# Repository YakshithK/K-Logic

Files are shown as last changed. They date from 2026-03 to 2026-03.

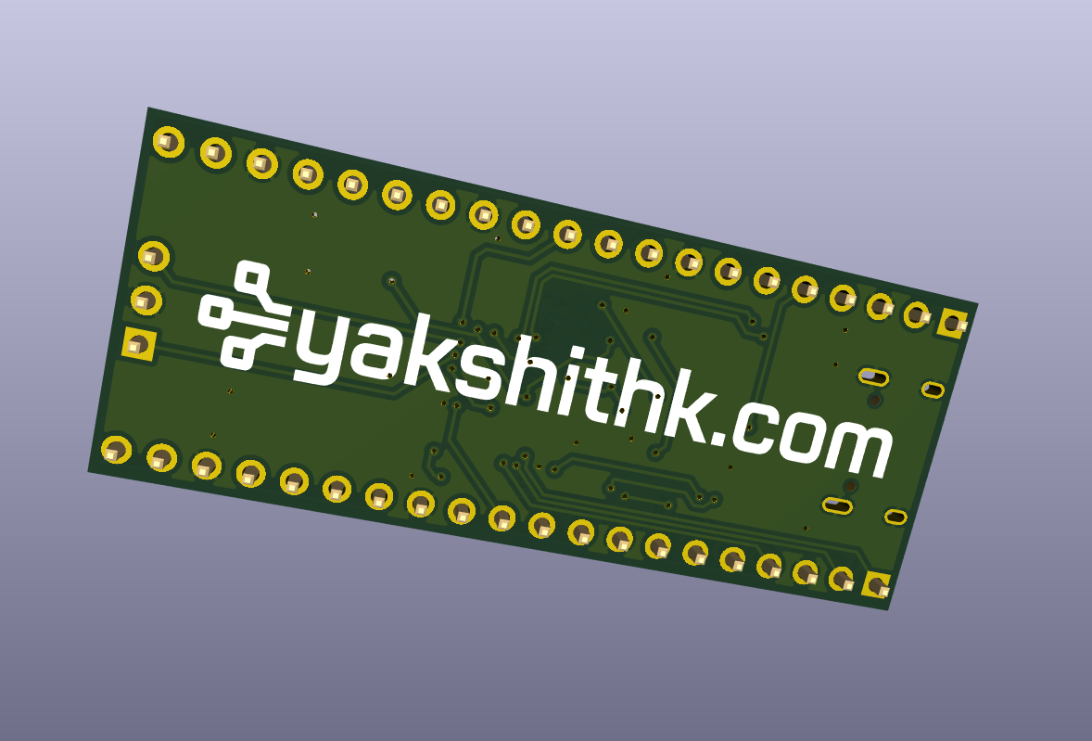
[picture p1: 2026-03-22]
Screenshots/Screenshot 2026-03-21 152902.png

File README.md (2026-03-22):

# K‑Logic Devboard

K‑Logic is a devboard I designed by following the Stasis starter devboard guide. my first PCB that goes! [stasis.hackclub](https://stasis.hackclub.com)

## What this is

- USB‑C powered devboard built with an RP2040
- Designed using the Stasis starter project flow (schematic → layout → silkscreen → fabrication)

## How to use it

- Plug it in over USB‑C.  
- Flash your firmware onto the main microcontroller.  
- Use the headers to hook up whatever logic / stuff you want.

## Why I built it

I've always wanted to get into hardware tech in general and I knew PCBs were going to be my first project in hardware after I found out about Stasis.

## Project structure

- `Journal/` – build log entries for each step (schematic, layout, silkscreen, fabrication, etc.). [github](https://github.com/YakshithK/K-Logic)
- `prod/` – production ZIP I sent to JLCPCB (gerbers + fab files). [github](https://github.com/YakshithK/K-Logic)
- `prod-files/` – BOM, CPL, and other manufacturing‑related files. [github](https://github.com/YakshithK/K-Logic)
- `DRC.rpt` – final DRC report from KiCad. [github](https://github.com/YakshithK/K-Logic)

## Screenshots

I have a bunch of screenshots of:

- Schematic in KiCad  
- PCB layout & 3D view  
- Silkscreen art and labels  
- JLCPCB upload / PCBA screens  

Check the `Screenshots/` dir

## BOM (short version)

Full BOM with links is in `K-Logic-Devboard-BOM-JLCPCB_Assembly_Order.csv` and `prod-files/`

| Part | Value | Notes |
| --- | --- | --- |
| MCU | (see BOM)  | Main brain of the board |
| Flash memory | W25Q16JVUXIQ | External flash for storage |
| USB‑C connector | — | Power + data input |
| LDO regulator | — | Regulates USB power |
| Passives | various | Resistors, caps, etc. |

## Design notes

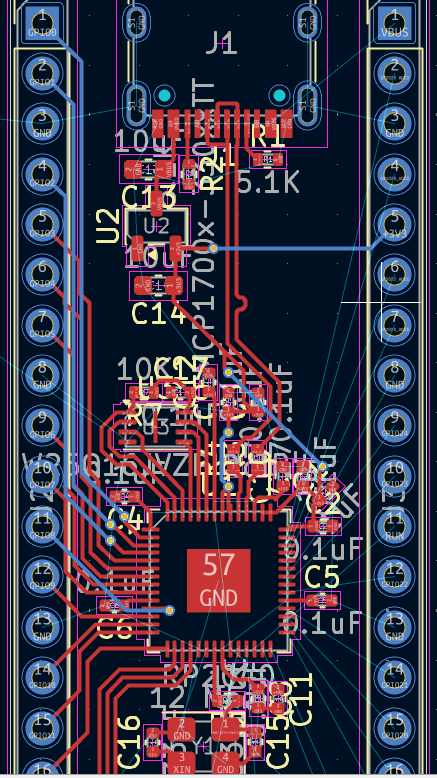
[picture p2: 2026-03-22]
Screenshots/Screenshot 2026-03-14 114329.png

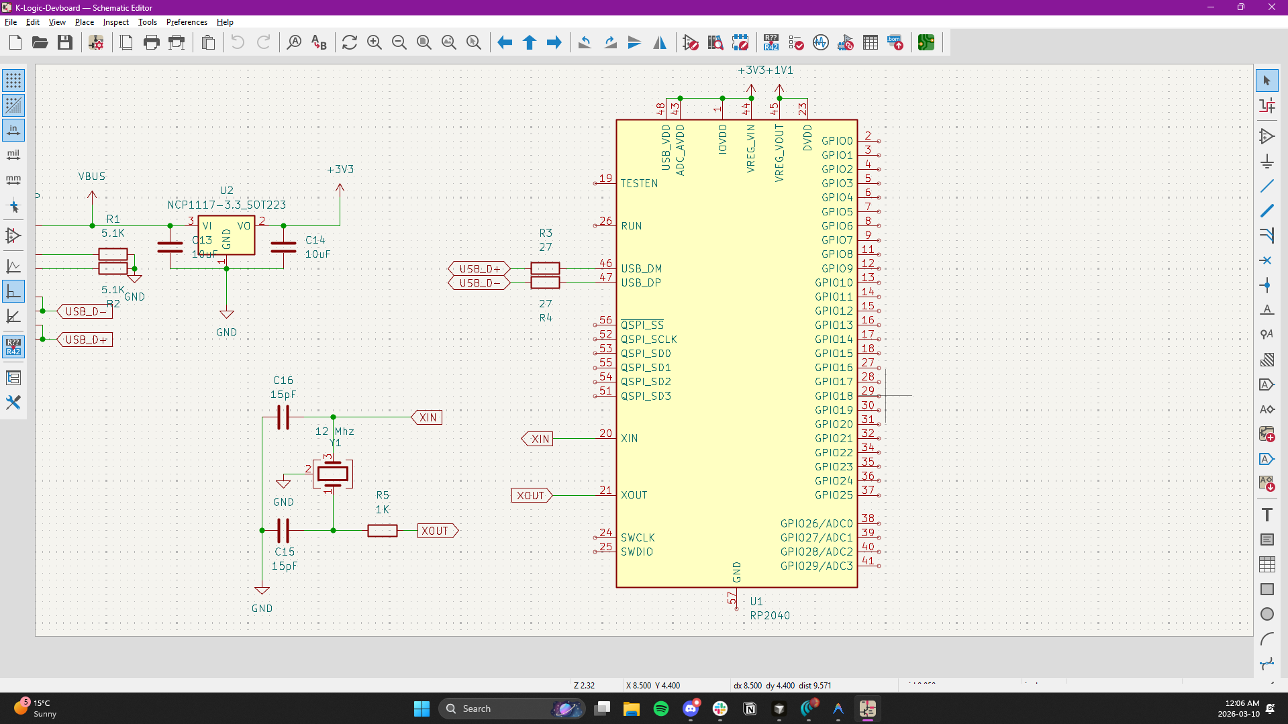
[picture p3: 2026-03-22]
Screenshots/Screenshot 2026-03-10 000638.png

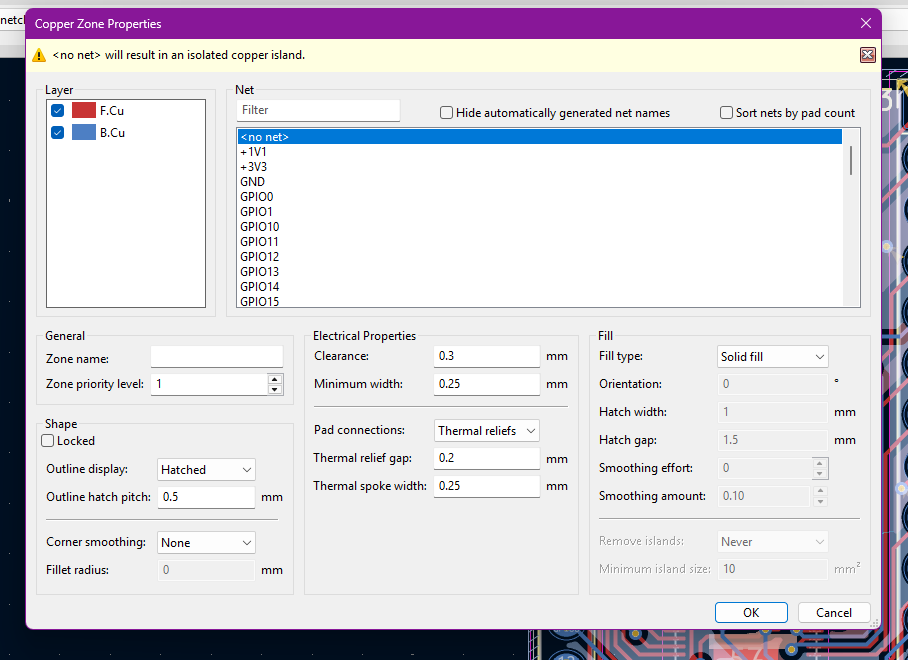
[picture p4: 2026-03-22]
Screenshots/Screenshot 2026-03-21 165424.png

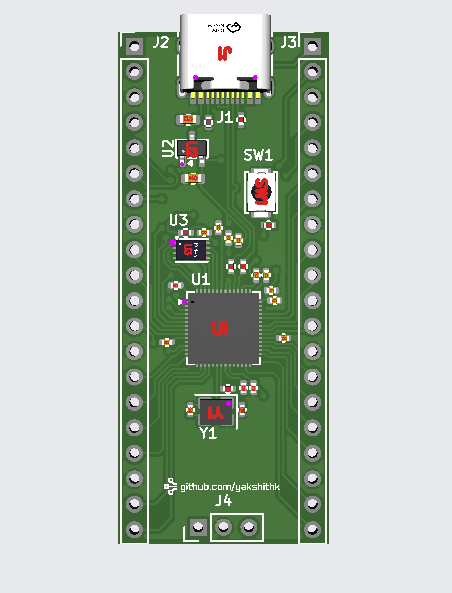
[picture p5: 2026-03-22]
Screenshots/Screenshot 2026-03-22 014045.png

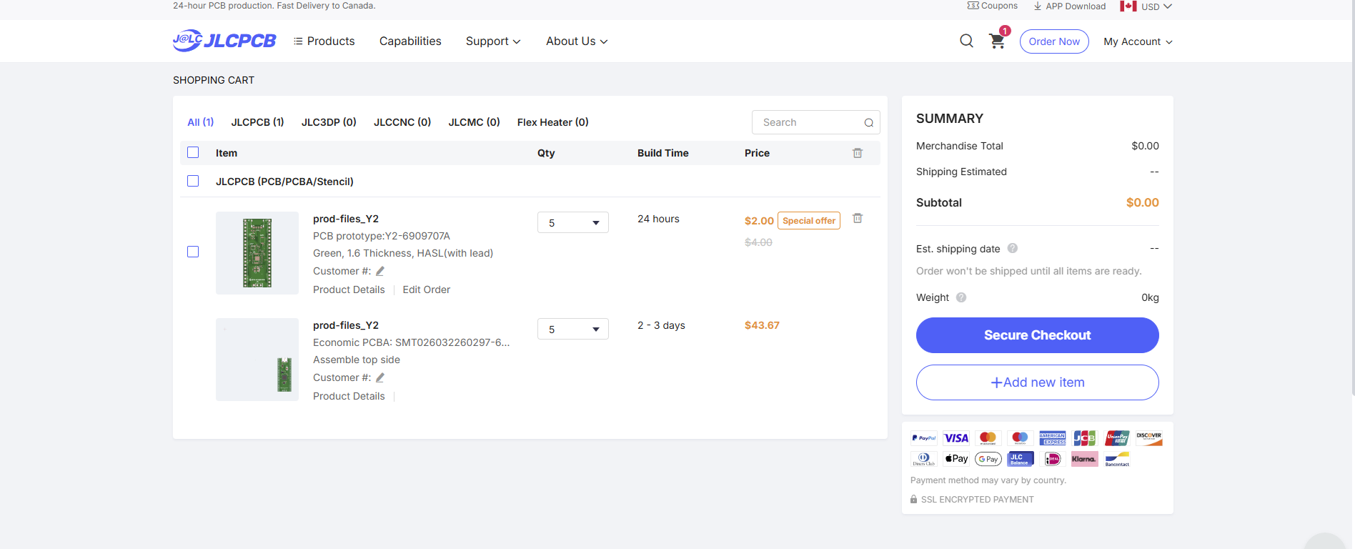
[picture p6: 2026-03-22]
Screenshots/Screenshot 2026-03-22 013410.png

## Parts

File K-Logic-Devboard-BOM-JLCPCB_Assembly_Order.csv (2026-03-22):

Top Designator | Bottom Designator | Comment | Footprint | JLCPCB Part # | Matches | Part # | Manufacturer | Footprint | Description | Category | Warning | JLCPCB Part # | Product link | Lib Type | Qty | Source | Total Price ($)
C10,C1 |  | 1uF | C_0402_1005Metric |  | Select by Customer | CL05A105KA5NQNC | Samsung Electro-Mechanics | 0402 | 1uF 25V X5R ±10% 0402 Multilayer Ceramic Capacitors MLCC - SMD/SMT ROHS | Multilayer Ceramic Capacitors MLCC - SMD/SMT |  | C52923 | https://jlcpcb.com/partdetail/53938-CL05A105KA5NQNC/C52923 | Basic | 20 | 20 JLCPCB | 0.08
C11,C5,C6,C2,C12,C9,C7,C17,C4,C8,C3 |  | 0.1uF | C_0402_1005Metric |  | Select by Customer | CL05B104KO5NNNC | Samsung Electro-Mechanics | 0402 | 100nF 16V X7R ±10% 0402 Multilayer Ceramic Capacitors MLCC - SMD/SMT ROHS | Multilayer Ceramic Capacitors MLCC - SMD/SMT | 1.The comment (CL05B104KO5NNNC) of this part does not match the one (0.1uF) provided in your BOM. Please confirm; | C1525 | https://jlcpcb.com/partdetail/1877-CL05B104KO5NNNC/C1525 | Basic | 65 | 65 JLCPCB | 0.0845
C14,C13 |  | 10uF | C_0603_1608Metric |  | Select by Customer | CL10A106KP8NNNC | Samsung Electro-Mechanics | 0603 | 10V 10uF X5R ±10% 0603 Multilayer Ceramic Capacitors MLCC - SMD/SMT ROHS | Multilayer Ceramic Capacitors MLCC - SMD/SMT |  | C19702 | https://jlcpcb.com/partdetail/20411-CL10A106KP8NNNC/C19702 | Basic | 20 | 20 JLCPCB | 0.144
C16,C15 |  | 33pF | C_0402_1005Metric |  | Select by Customer | 0402CG330J500NT | FH (Guangdong Fenghua Advanced Tech) | 0402 | 33pF 50V C0G ±5% 0402 Multilayer Ceramic Capacitors MLCC - SMD/SMT ROHS | Multilayer Ceramic Capacitors MLCC - SMD/SMT |  | C1562 | https://jlcpcb.com/partdetail/1914-0402CG330J500NT/C1562 | Basic | 20 | 20 JLCPCB | 0.024
J1 |  | USB_C_Receptacle_USB2.0_14P | USB_C_Receptacle_HRO_TYPE-C-31-M-12 |  | Select by Customer | TYPE-C-31-M-12 | Korean Hroparts Elec | SMD | -30℃~+80℃ 1 10,000 cycles 16P 20V 5A 7.35mm Female Surface Mount, Right Angle Type-C SMD USB Connectors ROHS | USB Connectors |  | C165948 | https://jlcpcb.com/partdetail/Korean_HropartsElec-TYPE_C_31_M12/C165948 | Extended | 5 | 5 JLCPCB | 0.906
J3,J2 |  | Conn_01x20 | PinHeader_1x20_P2.54mm_Vertical |  | Select by Customer | 2.54-1*20P直针 | BOOMELE(Boom Precision Elec) | 插件,P=2.54mm | -40℃~+105℃ 1 1x20P 2.54mm 20P 3A Black Brass Pin Header Through Hole Plugin,P=2.54mm Pin Headers ROHS | Pin Headers |  | C50981 | https://jlcpcb.com/partdetail/51993-2_54_1_20P/C50981 | Extended | 0 | 0 JLCPCB | 0
J4 |  | Conn_01x03 | PinHeader_1x03_P2.54mm_Vertical |  | Select by Customer | 1.27-1*3P针 | BOOMELE(Boom Precision Elec) | 插件,P=1.27mm | -55℃~+105℃ 1 1.27mm 1.7mm 1x3P 2.5mm 3A 3P 3mm Black Brass Pin Header Through Hole Plugin,P=1.27mm Pin Headers ROHS | Pin Headers |  | C24980 | https://jlcpcb.com/partdetail/25717-1_27_1_3P/C24980 | Extended | 0 | 0 JLCPCB | 0
R2,R1 |  | 5.1K | R_0402_1005Metric |  | Select by Customer | 0402WGF5101TCE | UNI-ROYAL(Uniroyal Elec) | 0402 | -55℃~+155℃ 5.1kΩ 50V 62.5mW Thick Film Resistor ±1% ±100ppm/℃ 0402 Chip Resistor - Surface Mount ROHS | Chip Resistor - Surface Mount |  | C25905 | https://jlcpcb.com/partdetail/26648-0402WGF5101TCE/C25905 | Basic | 20 | 20 JLCPCB | 0.016
R4,R3 |  | 27 | R_0402_1005Metric |  | Select by Customer | 0402WGF270JTCE | UNI-ROYAL(Uniroyal Elec) | 0402 | -55℃~+155℃ 27Ω 50V 62.5mW Thick Film Resistor ±1% ±100ppm/℃ 0402 Chip Resistor - Surface Mount ROHS | Chip Resistor - Surface Mount | 1.The comment (0402WGF270JTCE) of this part does not match the one (27) provided in your BOM. Please confirm; | C25100 | https://jlcpcb.com/partdetail/25843-0402WGF270JTCE/C25100 | Extended | 22 | 22 JLCPCB | 0.0176
R5,R6 |  | 1K | R_0402_1005Metric |  | Select by Customer | 0402WGF1001TCE | UNI-ROYAL(Uniroyal Elec) | 0402 | -55℃~+155℃ 1kΩ 50V 62.5mW Thick Film Resistor ±1% ±100ppm/℃ 0402 Chip Resistor - Surface Mount ROHS | Chip Resistor - Surface Mount | 1.The comment (0402WGF1001TCE) of this part does not match the one (1K) provided in your BOM. Please confirm; | C11702 | https://jlcpcb.com/partdetail/12256-0402WGF1001TCE/C11702 | Basic | 20 | 20 JLCPCB | 0.014
R7 |  | 10K | R_0402_1005Metric |  | Select by Customer | 0402WGF1002TCE | UNI-ROYAL(Uniroyal Elec) | 0402 | -55℃~+155℃ 10kΩ 50V 62.5mW Thick Film Resistor ±1% ±100ppm/℃ 0402 Chip Resistor - Surface Mount ROHS | Chip Resistor - Surface Mount | 1.The comment (0402WGF1002TCE) of this part does not match the one (10K) provided in your BOM. Please confirm; | C25744 | https://jlcpcb.com/partdetail/26487-0402WGF1002TCE/C25744 | Basic | 20 | 20 JLCPCB | 0.016
SW1 |  | SW_Push | SW_Push_SPST_NO_Alps_SKRK |  | Select by Customer | TS-1088-AR02016 | XUNPU | SMD,4x3mm | -30℃~+80℃ 1.6N 100,000 cycles 12V 2mm 3mm 4mm 50mA Black Round Button SMD(SMT) Tab SPST Surface Mount,Vertical Without Bracket SMD,4x3mm Tactile Switches ROHS | Tactile Switches |  | C720477 | https://jlcpcb.com/partdetail/XUNPU-TS_1088AR02016/C720477 | Basic | 9 | 9 JLCPCB | 0.4815
U1 |  | RP2040 | QFN-56-1EP_7x7mm_P0.4mm_EP3.2x3.2mm |  | Select by Customer | RP2040 | Raspberry Pi | LQFN-56(7x7) | 12bit 133MHz 30 LQFN-56(7x7) Microcontrollers (MCU/MPU/SOC) ROHS | Microcontrollers (MCU/MPU/SOC) |  | C2040 | https://jlcpcb.com/partdetail/RaspberryPi-RP2040/C2040 | Extended | 5 | 5 JLCPCB | 4.8295
U2 |  | MCP1700x-330xxTT | SOT-23-3 |  | Select by Customer | MCP1700T-3302E/TT | Microchip Tech | SOT-23 | -40℃~+125℃@(Tj) 1 1.6uA 178mV@(250mA) 250mA 3.3V 44dB@(100Hz) 6V Fixed Over Temperature Protection、Short Circuit Protection Positive SOT-23 Voltage Regulators - Linear, Low Drop Out (LDO) Regulators ROHS | Voltage Regulators - Linear, Low Drop Out (LDO) Regulators |  | C39051 | https://jlcpcb.com/partdetail/MicrochipTech-MCP1700T_3302ETT/C39051 | Extended | 5 | 5 JLCPCB | 1.864
U3 |  | W25Q16JVZPIQTR | Winbond_USON-8-1EP_3x2mm_P0.5mm_EP0.2x1.6mm |  | Select by Customer | W25Q16JVUXIQ | Winbond Elec | USON-8-EP(2x3) | -40℃~+85℃ 100,000 cycles 10uA 133MHz 16Mbit 2.7V~3.6V 20 Years 3ms SPI USON-8-EP(2x3) NOR FLASH ROHS | NOR FLASH | 1.The comment (W25Q16JVUXIQ) of this part does not match the one (W25Q16JVZPIQTR) provided in your BOM. Please confirm; | C2843335 | https://jlcpcb.com/partdetail/WinbondElec-W25Q16JVUXIQ/C2843335 | Extended | 5 | 5 JLCPCB | 8.331
Y1 |  | 12Mhz | Crystal_SMD_3225-4Pin_3.2x2.5mm |  | Select by Customer | X322512MSB4SI | YXC Crystal Oscillators | SMD3225-4P | -40℃~+85℃ 12MHz 20pF Crystal Oscillator ±10ppm ±20ppm SMD3225-4P Crystals ROHS | Crystals |  | C9002 | https://jlcpcb.com/partdetail/YXC_CrystalOscillators-X322512MSB4SI/C9002 | Basic | 9 | 9 JLCPCB | 0.6534

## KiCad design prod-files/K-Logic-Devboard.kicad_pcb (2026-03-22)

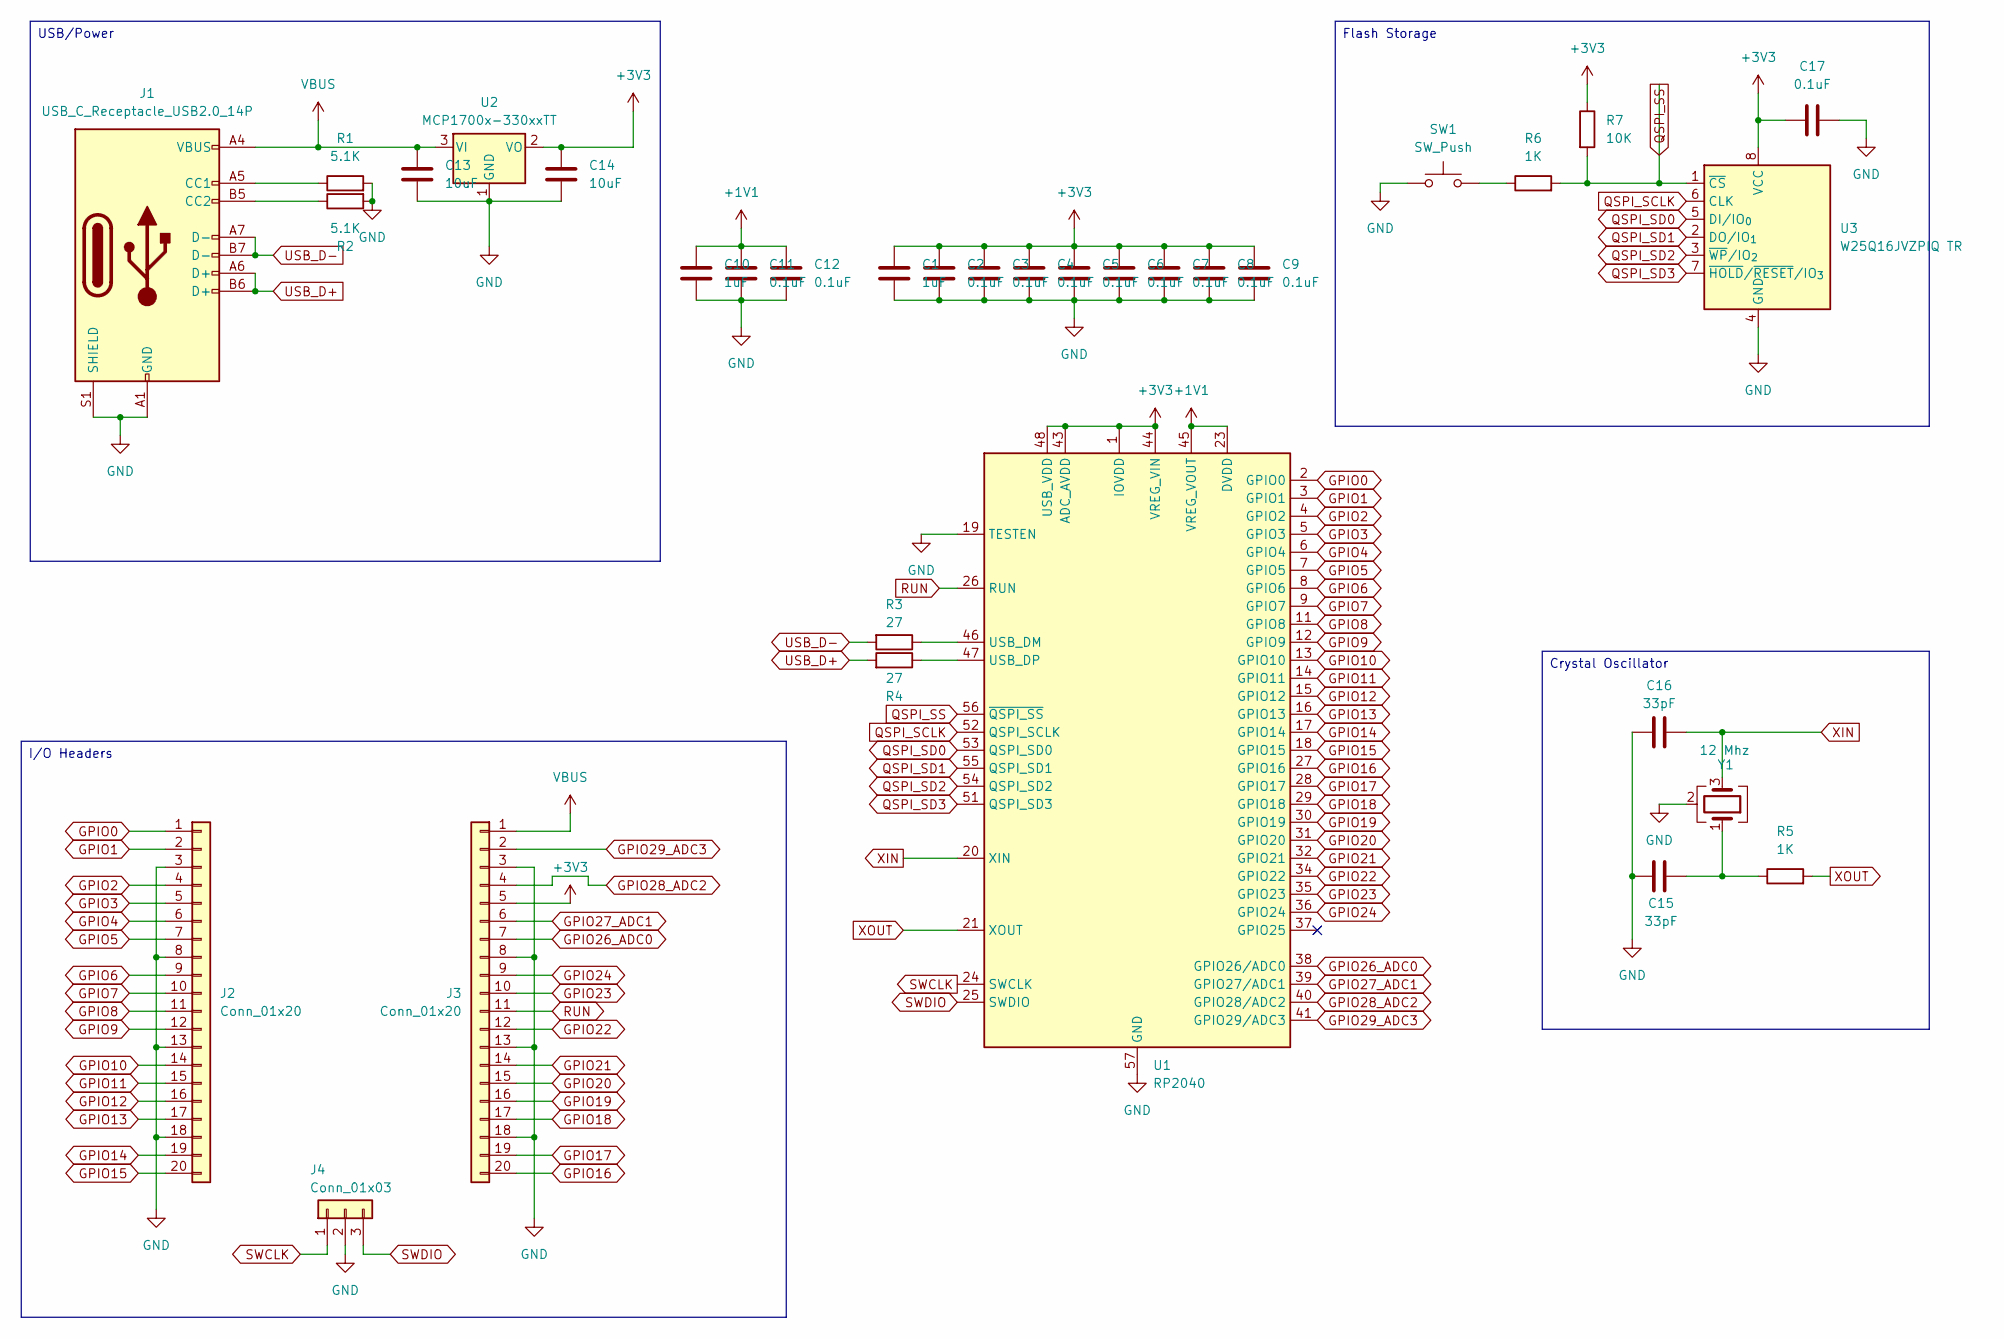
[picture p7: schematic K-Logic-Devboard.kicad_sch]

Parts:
C1, C10: 1uF; C_0402_1005Metric
C2, C3, C4, C5, C6, C7, C8, C9, C11, C12, C17: 0.1uF; C_0402_1005Metric
C13, C14: 10uF; C_0603_1608Metric
C15, C16: 33pF; C_0402_1005Metric
J1: USB_C_Receptacle_USB2.0_14P; USB_C_Receptacle_HRO_TYPE-C-31-M-12
J2, J3: Conn_01x20; PinHeader_1x20_P2.54mm_Vertical
J4: Conn_01x03; PinHeader_1x03_P2.54mm_Vertical
R1, R2: 5.1K; R_0402_1005Metric
R3, R4: 27; R_0402_1005Metric
R5, R6: 1K; R_0402_1005Metric
R7: 10K; R_0402_1005Metric
SW1: SW_Push; SW_Push_SPST_NO_Alps_SKRK
U1: RP2040; QFN-56-1EP_7x7mm_P0.4mm_EP3.2x3.2mm
U2: MCP1700x-330xxTT; SOT-23-3
U3: W25Q16JVZPIQ TR; Winbond_USON-8-1EP_3x2mm_P0.5mm_EP0.2x1.6mm
Y1: 12 Mhz; Crystal_SMD_3225-4Pin_3.2x2.5mm

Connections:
+1V1: C10.1, C11.1, C12.1, U1.23 (DVDD), U1.45 (VREG_VOUT), U1.50 (DVDD)
+3V3: C1.1, C2.1, C3.1, C4.1, C5.1, C6.1, C7.1, C8.1, C9.1, C14.1, C17.2, J3.5, R7.1, U1.1 (IOVDD), U1.10 (IOVDD), U1.22 (IOVDD), U1.33 (IOVDD), U1.42 (IOVDD), U1.43 (ADC_AVDD), U1.44 (VREG_VIN), U1.48 (USB_VDD), U1.49 (IOVDD), U2.2 (VO), U3.8 (VCC)
GND: C1.2, C2.2, C3.2, C4.2, C5.2, C6.2, C7.2, C8.2, C9.2, C10.2, C11.2, C12.2, C13.2, C14.2, C15.2, C16.2, C17.1, J1.A1 (GND), J1.A12 (GND), J1.B1 (GND), J1.B12 (GND), J1.S1 (SHIELD), J2.3, J2.8, J2.13, J2.18, J3.3, J3.8, J3.13, J3.18, J4.2, R1.2, R2.2, SW1.1, U1.19 (TESTEN), U1.57 (GND), U2.1 (GND), U3.4 (GND), Y1.2 (G), Y1.4 (G)
GPIO0: J2.1, U1.2 (GPIO0)
GPIO1: J2.2, U1.3 (GPIO1)
GPIO2: J2.4, U1.4 (GPIO2)
GPIO3: J2.5, U1.5 (GPIO3)
GPIO4: J2.6, U1.6 (GPIO4)
GPIO5: J2.7, U1.7 (GPIO5)
GPIO6: J2.9, U1.8 (GPIO6)
GPIO7: J2.10, U1.9 (GPIO7)
GPIO8: J2.11, U1.11 (GPIO8)
GPIO9: J2.12, U1.12 (GPIO9)
GPIO10: J2.14, U1.13 (GPIO10)
GPIO11: J2.15, U1.14 (GPIO11)
GPIO12: J2.16, U1.15 (GPIO12)
GPIO13: J2.17, U1.16 (GPIO13)
GPIO14: J2.19, U1.17 (GPIO14)
GPIO15: J2.20, U1.18 (GPIO15)
GPIO16: J3.20, U1.27 (GPIO16)
GPIO17: J3.19, U1.28 (GPIO17)
GPIO18: J3.17, U1.29 (GPIO18)
GPIO19: J3.16, U1.30 (GPIO19)
GPIO20: J3.15, U1.31 (GPIO20)
GPIO21: J3.14, U1.32 (GPIO21)
GPIO22: J3.12, U1.34 (GPIO22)
GPIO23: J3.10, U1.35 (GPIO23)
GPIO24: J3.9, U1.36 (GPIO24)
GPIO26_ADC0: J3.7, U1.38 (GPIO26/ADC0)
GPIO27_ADC1: J3.6, U1.39 (GPIO27/ADC1)
GPIO28_ADC2: J3.4, U1.40 (GPIO28/ADC2)
GPIO29_ADC3: J3.2, U1.41 (GPIO29/ADC3)
unnamed: C15.1, R5.1, Y1.1
unnamed: J1.A5 (CC1), R1.1
unnamed: J1.B5 (CC2), R2.1
unnamed: R6.1, SW1.2
unnamed: R3.1, U1.46 (USB_DM)
unnamed: R4.1, U1.47 (USB_DP)
QSPI_SCLK: U1.52 (QSPI_SCLK), U3.6 (CLK)
QSPI_SD0: U1.53 (QSPI_SD0), U3.5 (DI/IO_{0})
QSPI_SD1: U1.55 (QSPI_SD1), U3.2 (DO/IO_{1})
QSPI_SD2: U1.54 (QSPI_SD2), U3.3 (~WP/IO_{2})
QSPI_SD3: U1.51 (QSPI_SD3), U3.7 (~HOLD/~RESET/IO_{3})
QSPI_SS: R6.2, R7.2, U1.56 (~QSPI_SS), U3.1 (~CS)
RUN: J3.11, U1.26 (RUN)
SWCLK: J4.1, U1.24 (SWCLK)
SWDIO: J4.3, U1.25 (SWDIO)
USB_D+: J1.A6 (D+), J1.B6 (D+), R4.2
USB_D-: J1.A7 (D-), J1.B7 (D-), R3.2
VBUS: C13.1, J1.A4 (VBUS), J1.A9 (VBUS), J1.B4 (VBUS), J1.B9 (VBUS), J3.1, U2.3 (VI)
XIN: C16.1, U1.20 (XIN), Y1.3
XOUT: R5.2, U1.21 (XOUT)

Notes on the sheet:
Crystal Oscillator
I/O Headers
USB/Power
Flash Storage

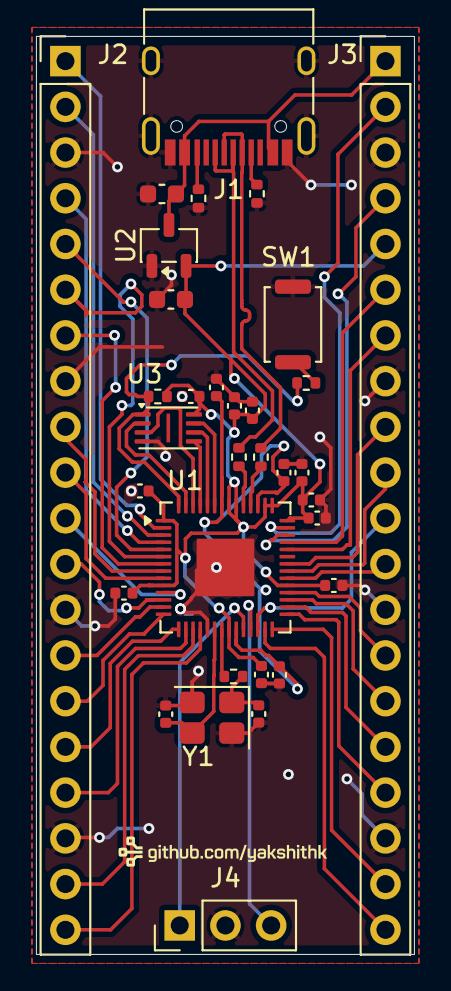
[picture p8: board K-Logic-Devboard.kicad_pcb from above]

Board: 2 copper layers, 21.0 x 51.0 mm, 33 parts (0 on the bottom side), 52 nets.

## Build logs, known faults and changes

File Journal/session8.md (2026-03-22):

#BOM + JLCPCB order

fabrication time for the board. exported all the outputs from kicad, grabbed the gerbers, bom, cpl, the whole thing. opened the cpl csv in sheets. ipped everything into a “production” folder and tossed it into jlcpcb’s quote page, turned on pcba so they actually assemble it. uploaded the bom + cpl, fixed the missing / wrong parts, especially the 27 ohm resistors and flash chip part number, and made sure headers are not selected for assembly. tweaked parts to use as many basic ones as possible so the price doesn’t blow up. then checked the 3d view / placement, nudged usb‑c, ldo, and flash so they line up right and match the markings, and saved to cart

db428c0efb5347bcb7ef50cb9205ec7b_T





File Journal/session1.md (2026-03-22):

#First Entry for K-Logic Devboard

This was my first PCB project so I spent the first 15-20 minutes researching what they are, what different terms mean and what the different pins on the board do.

After that I started working on the schematic for my devboard based off of the tutorial. Schematic = blueprint for your design before you actually start the design.

USBC for the power Crystal Oscilator for the clock system (didn't know computers know the time from rocks lol) SOC = System on a Chip, brain of the PCB. Flash Storage to store info





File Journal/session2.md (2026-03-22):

#worked on flash storage, i/o headers and footprints

In this session I worked on laying out the schematic for the Flash Storage (also watched a video about it while doing it), the input and output headers and I picked out the footprints for the parts based on the tutorial + doing some research on jlcpcb.

overall this session was a mix of learning, copying the things (intentionally ofc), and making weird design decisions that i have no idea will look like when this board is real and I’m holding it in my hands instead of just staring at kicad screenshots.





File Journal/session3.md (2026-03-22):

#started putting together the pcb design





in this session i started working on the actual design of the pcb, and grouping the components together and finally putting all the compoenents in the rectangle. A lot of the time went into moving parts around, thinking about where caps are supposed to go, and trying not to paint myself into a corner for routing later. i hit a wall near the end with how I’m supposed to place and wire all the decoupling capscorrectly, so ig im leaving that as the main problem to work on in the next session

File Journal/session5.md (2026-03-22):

#finished routing finally







In this session I finally finished the routing. I learned how to use vias and when not to use them, I noticed that routing each section from the top-most and made my life wayeasier, so I leaned into that pattern and used it to route teh rest of the board. Throughout the session, I could feel myself getting more used ti kicad, specifically via placement, routing, and how to keep things both work and also look nice.

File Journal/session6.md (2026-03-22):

#ground fill and fixing annoying red errors

session all about making the board less wires and more like actual pcb and honestly it was kinda confusing but also cool at the same time. i learned about this thing called a ground fill which is basically just dumping a big pool of copper all over the board instead of routing a million separate ground traces by hand. you grab the filled zone tool, set the net to gnd, turn it on for both layers, and use thermal reliefs so soldering later isn’t total hell with the copper just sucking all the heat away. then you smash b and like most of the gnd ratlines just disappear and suddenly the board looks way less like spaghetti and more like something you’d actually get from a fab.

after that it was just fighting the drc, i fucking hate drc. i ran the check and it spat out a stupid number of errors, most of them because of the ground pour being slightly wrong or pads not actually connecting how kicad wanted. i messed with the thermal relief gap and clearance to pull the fill closer, then started[ i spent too much time tryna solve drc errors lol](https://hackclub.slack.com/archives/C09HSQM550A/p1773702418651709)







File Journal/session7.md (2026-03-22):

#worked on silkscreen







cleaned up the labels so it doesn’t look like  garbage anymore. i deleted all the random c and r labels that dont matter for actually building it and just kept the important ones like the pi header and connectors. after that i played around with the kicad image thing and added some my website + small logo on the front and back to make the board feel like mine, not just some template. ran drc again at the end just to make sure i didnt accidentally put text on top of pads or break any clearances.

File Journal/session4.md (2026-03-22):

#worked on routing, took super long to route efficiently







Throughout this session, I routed the usb and its caps. This took a lot of time because I had to rearrange a lot of things to make sure all the routes fit and don't take any awkward sharp turns as shown in one of the images.

literally all the time was spent iterating: route a pair, see a cursed angle, undo, shift components, and try again until the USB lines and caps flowed in a way that felt proper instead of glued tg. i also paid extra attention to avoiding super sharp turns and awkward jogs, as apparently that messes with the signal or something according to the tutorial.

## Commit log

2026-03-10 worked on flash storage, i/o headers and footprints
    [K-Logic-Devboard.kicad_sch]
2026-03-11 third session: worked on the pcb design
    [K-Logic-Devboard.kicad_pcb, K-Logic-Devboard.kicad_sch]
2026-03-22 pcb 99.99% done. journals and BOM.
    [K-Logic-Devboard.kicad_pcb, K-Logic-Devboard.kicad_sch]
2026-03-22 we done
    [K-Logic-Devboard-BOM-JLCPCB_Assembly_Order.csv, K-Logic-Devboard-BOM-JLCPCB_Assembly_Order.xls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]
